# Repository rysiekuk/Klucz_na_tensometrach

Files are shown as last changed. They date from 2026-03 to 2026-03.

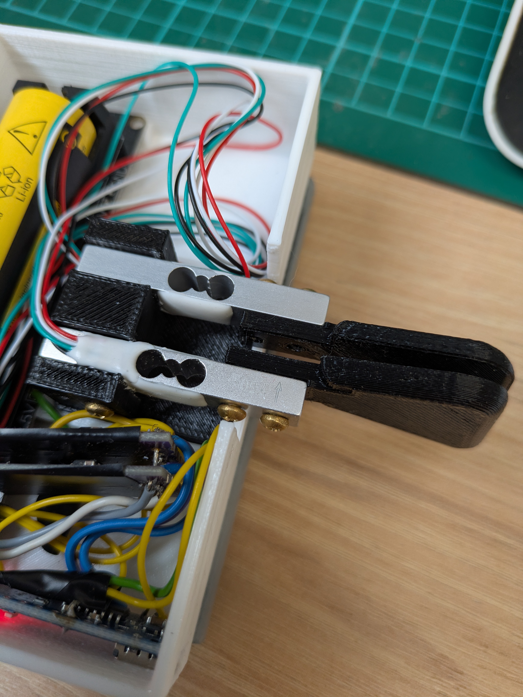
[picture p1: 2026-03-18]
750g_paddles.jpg

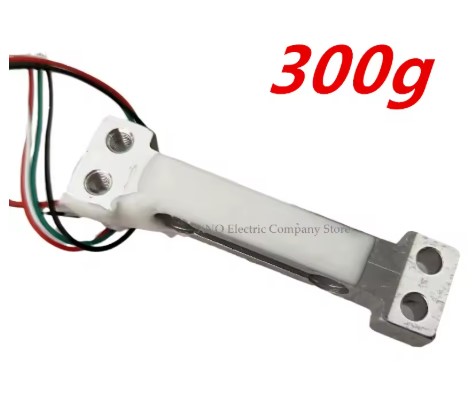
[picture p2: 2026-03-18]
300g_V_holes.jpg

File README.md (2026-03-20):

# Morse Paddle Trainer (Arduino)

Simple Arduino project for Morse key using pressure sensors (load cells).
The device measures the force applied to two paddles (DIT and DASH) and converts it to signals or audio output.

## Hardware

### Microcontroller

* Arduino Nano
  https://www.aliexpress.com/item/1665783181.html

### ADC Converters

* CS1237 24-bit ADC module ×2
  https://www.aliexpress.com/item/1005007150110287.html

### Sensors

 * Load cell 750 g ×2
   https://www.aliexpress.com/item/1644918827.html

### Audio Output

* 3.5 mm Audio Jack
  https://www.aliexpress.com/item/1005005562420070.html

### Power Supply

* 18650 Lithium Battery Shield V8
  https://www.aliexpress.com/item/1005006252337213.html

### Photorelay

* Photorelay TP175A  x2
  https://www.aliexpress.com/item/1005009826702202.html

### Jack 3.5 mm socket

* Jack 3.5 mm
  https://www.aliexpress.com/item/1005005562420070.html

## Features

* Measures force applied to Morse paddles
* Separate sensors for **DIT** and **DASH**
* 24-bit ADC for high precision measurement
* Adjustable thresholds
* Key output through 3.5 mm jack
* Battery powered (18650)

## Hardware Configuration

* Arduino Nano reads values from two CS1237 ADC modules
* Each ADC is connected to one load cell
* The system detects paddle pressure and generates Morse signals

## Possible Improvements

* EEPROM configuration storage
* Adjustable sensitivity
* USB configuration interface

## Author
M0RPA

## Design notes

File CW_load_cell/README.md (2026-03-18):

# Program do Kalibracji Klucza Morse'a

Ten program służy do kalibracji klucza Morse'a poprzez pomiar odczytów z czujnika i przeliczenie ich na factor_dit i factor_dash.  

## Uruchomienie

1. Podłącz klucz do portu szeregowego.
2. Uruchom program calibracja – na ekranie pojawi się aktualna wartość odczytana z belki.

## Instrukcja kalibracji

### 1. Kalibracja "dash" (długa kreska)

1. Ustaw klucz poprzecznie, łopatka z kreskami skierowana do góry.
2. Odczytaj wartość czujnika i zapisz jako `waga 0`.
3. Połóż na łopatkę monetę o znanej wadze i odczytaj wartość – zapisz jako `waga X gramów`.
4. Powtarzaj, dokładając kolejne monety i zapisując kolejne odczyty.
5. Calkowita waga około 50 gr

**Przykład dla monety 1-funtowej (waga 8.75 g):**

| Waga [g] | Odczyt |
|---|---|
| 0 | 90000  |
| 8.75 | 150000 |
| 17.5 | 200000 |

### 2. Obliczenie współczynnika dash

Dla każdej linii obliczamy wartość:

- Linie z 1 monetą: `(150000 - 90000) / 8,75 = 6 857`  
- Linie z 2 monetami: `(200000 - 90000) / (8,75 × 2) = 6 285`  

Z wyliczonych wartości przyjmujemy średnią, którą zapisujemy w `factor_dash`.

Dodany Excel do obliczen

---

### 3. Kalibracja "dit" (kropka)

1. Obróć klucz o 180° tak, aby łopatki kropek były skierowane do góry.  
2. Powtórz procedurę opisaną w sekcji 1–2, aby wyliczyć i zapisać `factor_dit`.

# Morse Key Calibration Program

This program is used to calibrate a Morse key by measuring sensor readings and converting them into `factor_dit` and `factor_dash`.

---

## Getting Started

1. Connect the Morse key to the serial port.  
2. Run the `calibracja` program – the current value from the key's lever will be displayed on the screen.

---

## Calibration Instructions

### 1. Dash ("–") Calibration

1. Position the key horizontally with the dash paddle facing up.  
2. Read the sensor value and record it as `weight 0`.  
3. Place a coin of known weight on the paddle and record the sensor reading as `weight X g`.  
4. Repeat by adding more coins and recording each reading.  
5. Total weight should be approximately 50 g.

**Example for a 1-pound coin (weight 8.75 g):**

| Weight [g] | Sensor Reading |
|---|---|
| 0 | 90,000 |
| 8.75 | 150,000 |
| 17.5 | 200,000 |

---

### 2. Calculating the Dash Factor

For each measurement, calculate the value:

- Single-coin line: `(150000 - 90000) / 8.75 = 6,857`  
- Two-coin line: `(200000 - 90000) / (8.75 × 2) = 6,285`  

The average of the calculated values is assigned to `factor_dash`.

---

### 3. Dit ("·") Calibration

1. Rotate the key 180° so that the dot paddle faces up.  
2. Repeat the procedure from sections 1–2 to calculate and save `factor_dit`.

Added excel for calculation

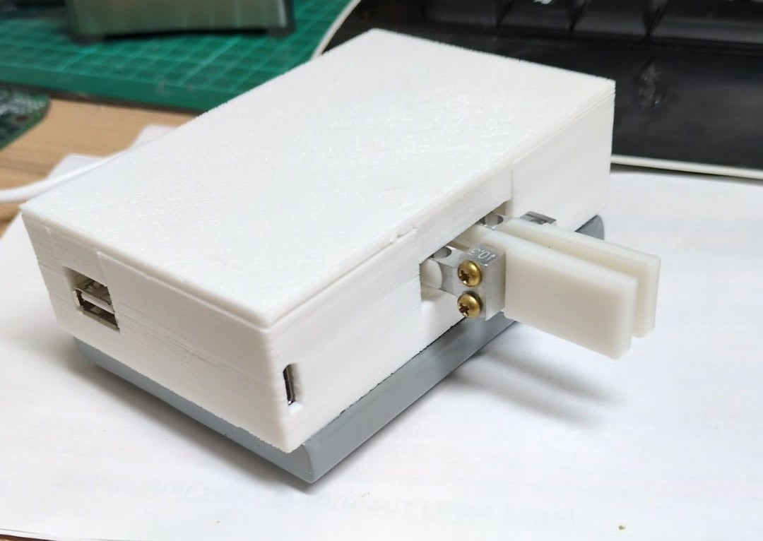
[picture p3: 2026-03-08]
klucz_cw.jpg

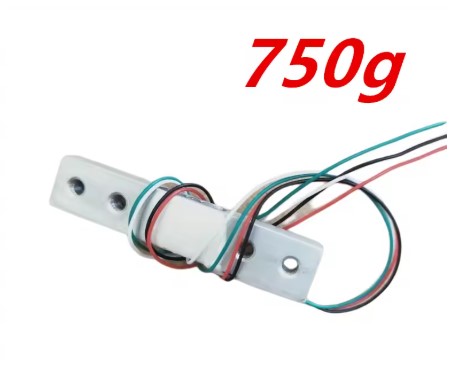
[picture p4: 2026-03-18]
750g_H_holes.jpg

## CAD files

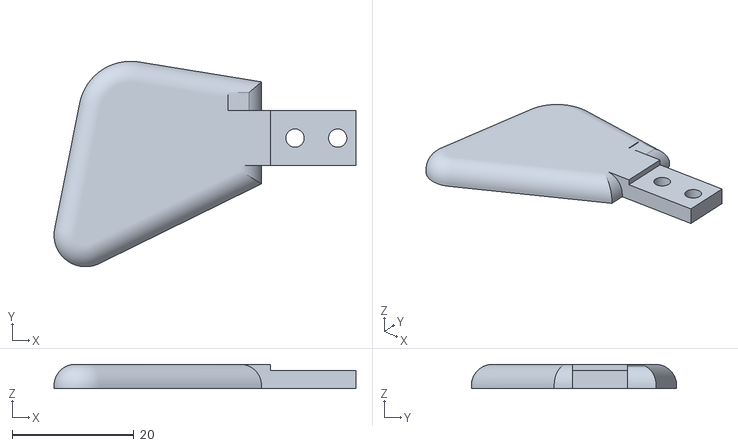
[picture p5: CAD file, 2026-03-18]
wioselko_prawe_H_holes.stl
49.5 x 33.7 x 4.00

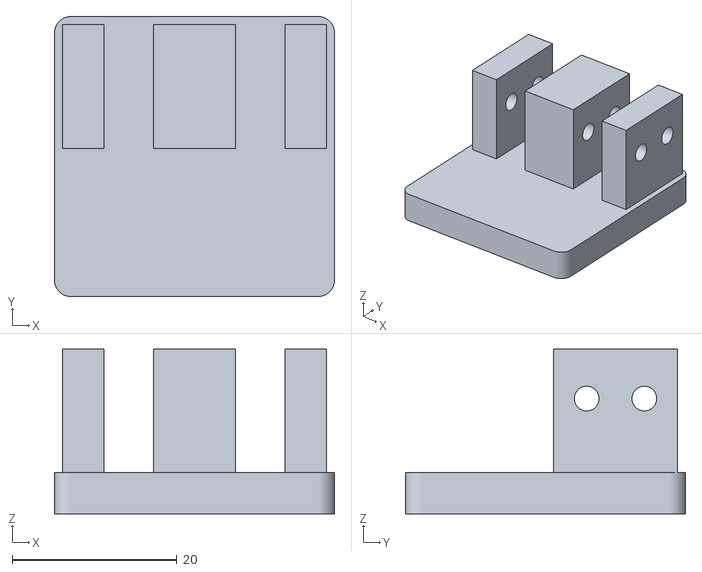
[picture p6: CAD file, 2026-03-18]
podstawa_belek_H_holes.stl
34.0 x 34.0 x 20.0

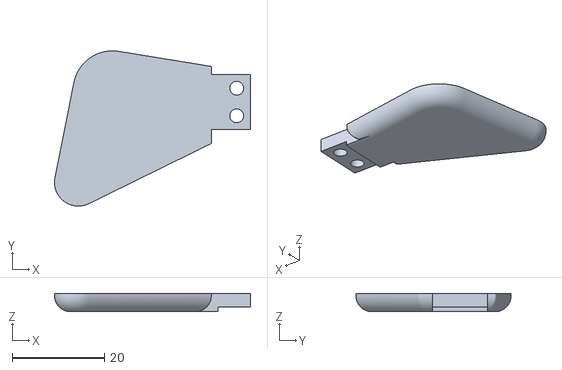
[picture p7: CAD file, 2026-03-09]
wioselko_lewe_V_holes.stl
42.5 x 33.7 x 4.00

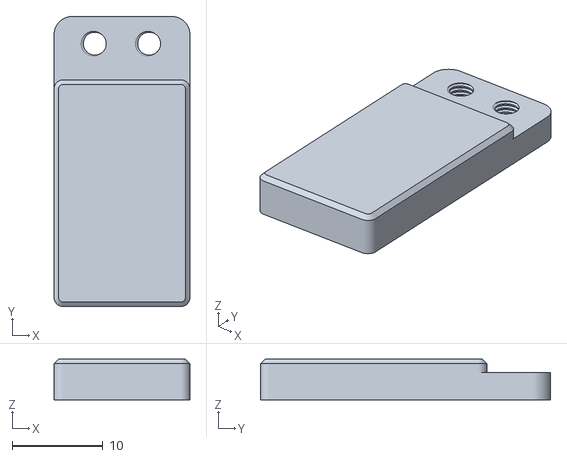
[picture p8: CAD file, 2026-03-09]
wioselko_prostokatne_V_holes.stl
15.0 x 32.0 x 4.50

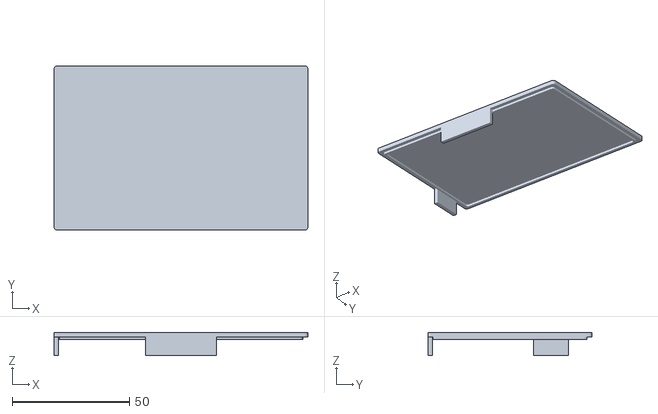
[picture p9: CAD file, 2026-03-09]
przykrywka.stl
108.3 x 70.0 x 10.0

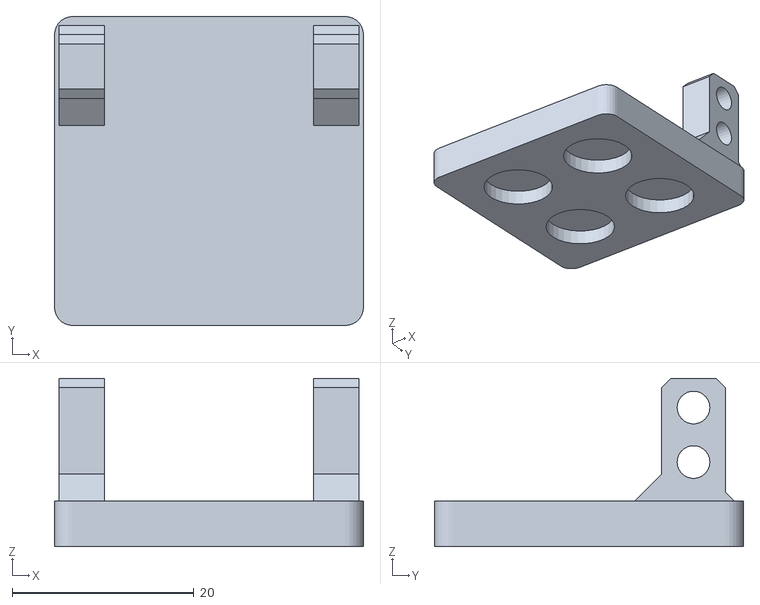
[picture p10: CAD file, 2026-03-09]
podstawa_belek_V_holes.stl
34.0 x 34.0 x 18.5

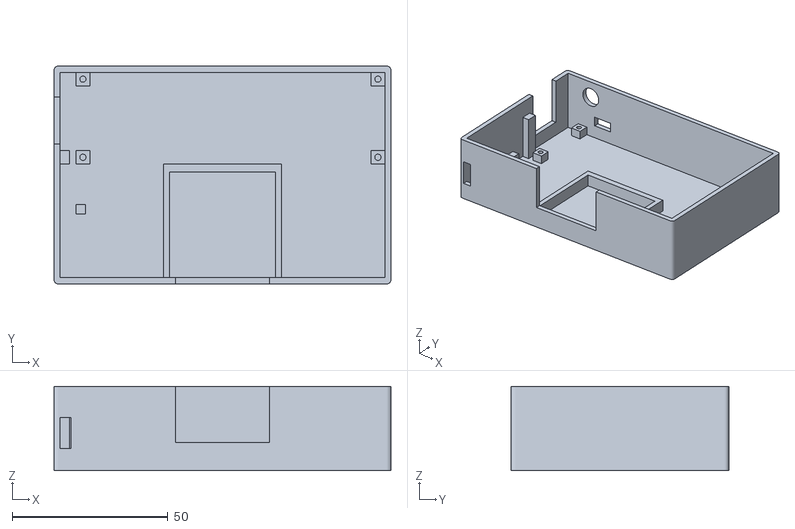
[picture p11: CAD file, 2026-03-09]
obudowa.stl
108.3 x 70.0 x 27.0

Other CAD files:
wioselko_lewe_H_holes.stl
wioselko_prawe_V_holes.stl

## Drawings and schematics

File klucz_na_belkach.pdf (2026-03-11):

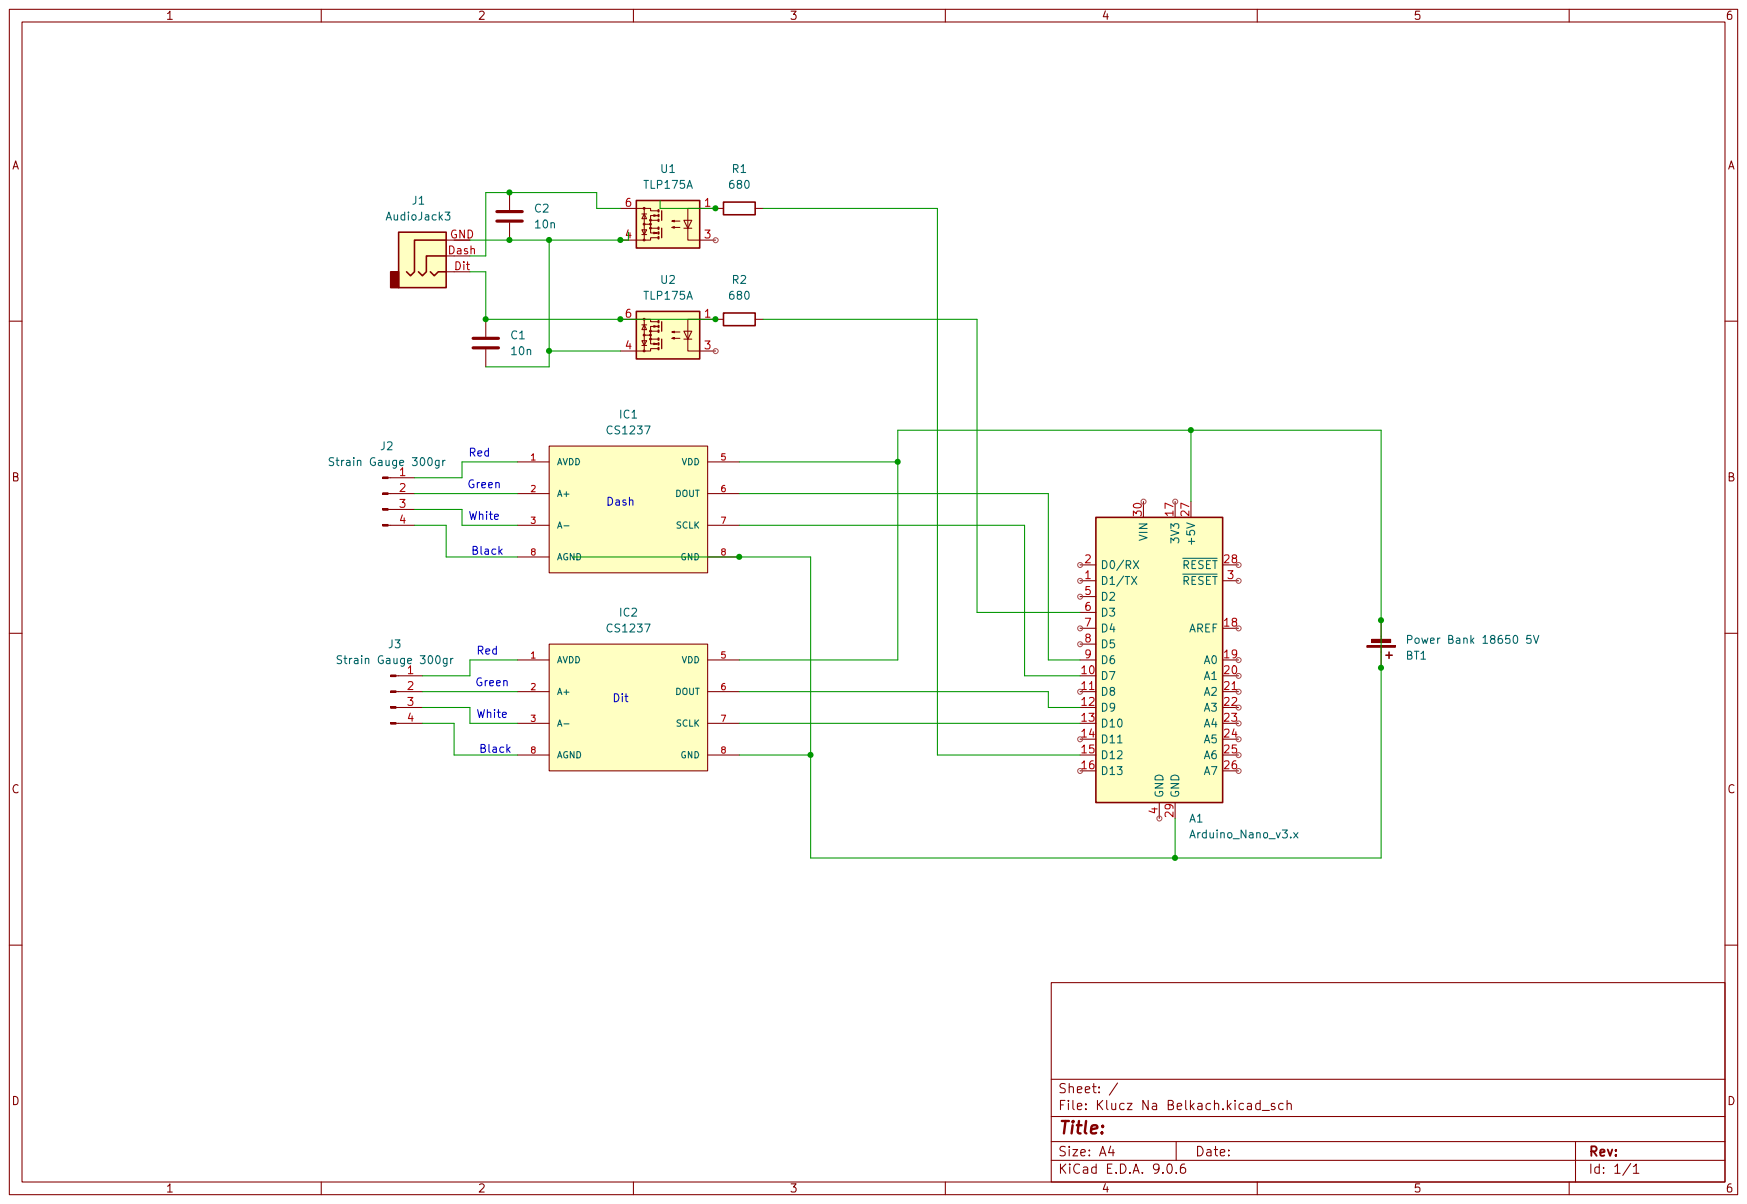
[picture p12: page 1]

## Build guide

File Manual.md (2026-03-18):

# Manual obsługi klucza Morse’a / Morse Key Manual

## Uruchomienie / Startup

Po starcie klucz automatycznie nadaje znak **R** na wyjściu (uwaga: wyłącz nadajnik TX, aby uniknąć zakłóceń).

Upon startup, the key automatically sends the **R** character to the output (note: turn off the TX transmitter to avoid interference).

## Skoki nacisku / Pressure Steps

Klucz posiada **10 skoków nacisku**, które wyzwalają osobne łopatki dla prawej i lewej strony.

The key has **10 pressure steps**, triggering separate paddles for the right and left sides.

* Każdy skok odpowiada wielokrotności **5 gramów** (5 g, 10 g, 15 g …).

* Each step corresponds to a multiple of **5 grams** (5 g, 10 g, 15 g …).

* Zmiana ustawienia następuje poprzez przytrzymanie łopatki aż do momentu, gdy klucz przestanie nadawać, a następnie jej puszczenie.

* Change the setting by holding the paddle until the key stops sending, then release it.

* Klucz nada ilość kresek lub kropek odpowiadającą aktualnemu ustawieniu.

* The key sends a number of dashes or dots corresponding to the current setting.

* Każde kolejne powtórzenie kroku zwiększa ustawienie o jeden stopień.

* Each repetition of this step increases the setting by one.

* Po osiągnięciu 10. skoku ustawienie wraca do 1.

* After reaching the 10th step, the setting resets to 1.

* Proces ten działa **osobno dla kropek i kresek**.

* This process works **separately for dots and dashes**.

## Zapisywanie ustawień do pamięci / Saving Settings to Memory

Aby zapisać ustawienia dla kropek i kresek w pamięci klucza:

To save the settings for dots and dashes in the key's memory:

1. Naciśnij łopatkę lewej lub prawej strony i przytrzymaj, aż nastąpi cisza.
2. Press the left or right paddle and hold until silence occurs.
3. Puść łopatkę i natychmiast naciśnij łopatkę po przeciwnej stronie, aby zakończyć zapis.
4. Release the paddle and immediately press the paddle on the opposite side to finish saving.

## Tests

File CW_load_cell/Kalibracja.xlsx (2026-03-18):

Waga monety
8.75
Ilosc monet | Wartosc Dit | Wartosc Dash
0 | 50000 | 0
1 | 72000 | 10000 | 2514.29 | 1142.86
2 | 92000 | 30000 | 2400.00 | 1714.29
3 | 115000 | 55000 | 2476.19 | 2095.24
4 | 130000 | 70000 | 2285.71 | 2000.00
5 | 160000 | 90000 | 2514.29 | 2057.14
 | 2438.095238 | 1801.904762

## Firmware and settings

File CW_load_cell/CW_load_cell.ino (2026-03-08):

#include "iarduino_ADC_CS1237.h" 
#include <EEPROM.h>
#define EEPROM_START 0
#define MAGIC_NUMBER 0x1977

iarduino_ADC_CS1237 adc1(10, 9);
iarduino_ADC_CS1237 adc2(7, 6); 

int32_t read_dit; 
int32_t read_dash;
int32_t calc_pressure_threshold_dit; 
int32_t calc_pressure_threshold_dash;
int counter_dit;
int counter_dash;
int32_t read_dash_value;
int32_t read_dit_value;
int32_t factor_dit = 6250;   
int32_t factor_dash = 6250; 



struct config_t { 
  int eeprom_magic_number;
  int grams_dit;
  int grams_dash;
} configuration;


void setup() {

  
counter_dit = 0;
counter_dash = 0;
pinMode(3, OUTPUT); // dit
pinMode(12, OUTPUT); // dash

Serial.begin(115200);
 
  int magic = readInt(EEPROM_START);
  if (magic != MAGIC_NUMBER) {
    Serial.println("EEPROM not initialized, writing default values...");
    initDefaultConfig();
  } else {
    Serial.println("EEPROM already initialized, reading values...");
    readConfig();
  }

  // Print values
  Serial.print("Magic: "); Serial.println(configuration.eeprom_magic_number, HEX);
  Serial.print("Grams Dit: "); Serial.println(configuration.grams_dit);
  Serial.print("Grams Dash: "); Serial.println(configuration.grams_dash);

  bool i; 
  pinMode(LED_BUILTIN, OUTPUT);
  adc1.setPulseWidth(30);
  // adc1.begin();
  i = adc1.begin();
  if (!i) { Serial.print(F("\n\r adc1 not present ")); }
  adc1.setPinVrefOut(true);
  adc1.setVrefIn(5.0);
  adc1.setSpeed(640);
  adc1.setPGA(2);
  adc1.setChannel(0);

  adc2.setPulseWidth(30);
  //adc2.begin();
  i = adc2.begin();
  if (!i) { Serial.print(F("\n\r adc2 not present ")); }
  adc2.setPinVrefOut(true);
  adc2.setVrefIn(5.0);
  adc2.setSpeed(640);
  adc2.setPGA(2);
  adc2.setChannel(0);

  

  read_dash = (adc2.analogRead() / 1000) * 1000;
  read_dit = (adc1.analogRead() / 1000) * 1000;
 
  read_dash_value = read_dash;
  read_dit_value = read_dit;
  Serial.print(F("\n\r adc1 idle: "));
  Serial.print(read_dash);
  Serial.print(F("\n\r adc2 idle: "));
  Serial.println(read_dit);

  calc_pressure_threshold_dash = (configuration.grams_dash * factor_dash) + read_dash_value;
  Serial.println(calc_pressure_threshold_dash);
  calc_pressure_threshold_dit = (configuration.grams_dit * factor_dit) + read_dit_value;
  Serial.println(calc_pressure_threshold_dit);


  // R when ready

          digitalWrite(3, HIGH);
          delay(100);
          digitalWrite(3, LOW);
          delay(100);
          digitalWrite(12, HIGH);
          delay(100);
          digitalWrite(12, LOW);
          delay(100);
          digitalWrite(3, HIGH);
          delay(100);
          digitalWrite(3, LOW);
          delay(2500);




}




void loop() {
   
  read_dash = (adc2.analogRead() / 1000) * 1000;
  read_dit = (adc1.analogRead() / 1000) * 1000;
  Serial.print(F("\n\r waga dit: "));
  Serial.print((read_dit - read_dit_value) / factor_dit);
  Serial.print(F("\n\r waga dash: "));
  Serial.print((read_dash - read_dash_value) / factor_dash);
  Serial.print(F("\n\r grams dit: "));
  Serial.print(configuration.grams_dit);
  Serial.print(F("\n\r grams dash: "));
  Serial.println(configuration.grams_dash);


  
  
  if (read_dit > calc_pressure_threshold_dit) {
   
    digitalWrite(3, HIGH);
    counter_dit++;
    if (counter_dit == 200) {
      counter_dit = 0;
      digitalWrite(3, LOW);
      tara(1);
    }
  }
  else {
   
    digitalWrite(3, LOW);//extra
    counter_dit = 0;

  }  //
  if (read_dash > calc_pressure_threshold_dash) {
    
    digitalWrite(12, HIGH);
    counter_dash++;
    if (counter_dash == 200) {
      counter_dash = 0;
      digitalWrite(12, LOW);
      tara(2);
    }
  }
  else {
   
    digitalWrite(12, LOW);
    counter_dash = 0;  

  }  
 
  
}


 void tara(int paddle) {

  Serial.print("Tare");
  delay(2500);
  read_dash = (adc2.analogRead() / 1000) * 1000;
  read_dit = (adc1.analogRead() / 1000) * 1000;

  
  if (paddle == 2) {

          if (read_dit > calc_pressure_threshold_dit) {
          writeConfig();
          digitalWrite(12, HIGH);
          delay(100);
          digitalWrite(12, LOW);
          delay(2500);
          return;
          }
      
      configuration.grams_dash = configuration.grams_dash + 5;
        if (configuration.grams_dash == 50) {
          configuration.grams_dash = 5;
        }
    calc_pressure_threshold_dash = (configuration.grams_dash * factor_dash) + read_dash_value;
    
    for (int i = 0; i < configuration.grams_dash /5; i++) {
    digitalWrite(12, HIGH);
    delay(100);
    digitalWrite(12, LOW);
    delay(300);
    }
    



  }
  
  if (paddle == 1) {

          if (read_dash > calc_pressure_threshold_dash) {
          writeConfig();
          digitalWrite(3, HIGH);
          delay(100);
          digitalWrite(3, LOW);
          delay(2500);
          return;
          }

      configuration.grams_dit = configuration.grams_dit + 5;
        if (configuration.grams_dit == 50) {
          configuration.grams_dit = 5;
        }
    calc_pressure_threshold_dit = (configuration.grams_dit * factor_dit) + read_dit_value;

        for (int i = 0; i < configuration.grams_dit /5; i++) {
        digitalWrite(3, HIGH);
        delay(100);
        digitalWrite(3, LOW);
        delay(350);
        }
    
  }
  
}

// --- Helper functions ---
void writeInt(int address, int value) {
  EEPROM.write(address, (value >> 8) & 0xFF);
  EEPROM.write(address + 1, value & 0xFF);
}

int readInt(int address) {
  return (EEPROM.read(address) << 8) | EEPROM.read(address + 1);
}

void writeInt32(int address, int32_t value) {
  EEPROM.write(address, (value >> 24) & 0xFF);
  EEPROM.write(address + 1, (value >> 16) & 0xFF);
  EEPROM.write(address + 2, (value >> 8) & 0xFF);
  EEPROM.write(address + 3, value & 0xFF);
}

int32_t readInt32(int address) {
  return ((int32_t)EEPROM.read(address) << 24) |
         ((int32_t)EEPROM.read(address + 1) << 16) |
         ((int32_t)EEPROM.read(address + 2) << 8) |
         EEPROM.read(address + 3);
}

// --- Write the full config ---
void writeConfig() {
  int addr = EEPROM_START;
  writeInt(addr, configuration.eeprom_magic_number); addr += 2;
  writeInt(addr, configuration.grams_dit); addr += 2;
  writeInt(addr, configuration.grams_dash); addr += 2;
}

// --- Read the full config ---
void readConfig() {
  int addr = EEPROM_START;
  configuration.eeprom_magic_number = readInt(addr); addr += 2;
  configuration.grams_dit = readInt(addr); addr += 2;
  configuration.grams_dash = readInt(addr); addr += 2;
}

// --- Initialize default config ---
void initDefaultConfig() {
  configuration.eeprom_magic_number = MAGIC_NUMBER;
  configuration.grams_dit = 5;
  configuration.grams_dash = 5;

  writeConfig();
}

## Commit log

2026-03-11 Rename Wioselko Lewe.stl to wioselko_lewe.stl
    [wioselko_lewe.stl]
2026-03-11 Rename Wioselko prawe.stl to wioselko_prawe.stl
    [wioselko_prawe.stl]
2026-03-11 Rename podstawa belek.stl to podstawa_belek.stl
    [podstawa_belek.stl]
2026-03-11 Rename Wioselko prostokatne.stl to wioselko_prostokatne.stl
    [wioselko_prostokatne.stl]
2026-03-15 Enhance README with Morse key calibration details
    Updated the README to include detailed calibration instructions for Morse key, including calculations for dash and dit factors.
2026-03-18 Update README to remove 300 g load cell entry
    Removed the 300 g load cell from the sensors list.
2026-03-18 Fix sensor link formatting in README.md
